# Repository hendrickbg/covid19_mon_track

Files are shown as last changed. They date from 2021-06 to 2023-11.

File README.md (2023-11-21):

# Covid-19 Vaccine Monitoring and Tracking using iMCP HT32SX - Undergraduate Thesis

- Pontifical Catholic University of Rio Grande do Sul - Brazil <br/>
Computer Engineering Undergraduate Thesis  

- Author: Hêndrick Bataglin Gonçalves
- Year: 2021/1

<hr>

## Project

Undergraduate Thesis developed using [iMCP HT32SX](https://github.com/htmicron/ht32sx) and BlueNRG-LP.

<hr>

## How to Clone this Repository

```
git clone git@github.com:HendrickGoncalves/covid19_mon_track.git
```

<hr>

## Hyper Links:

* [Firmware Project](Firmware_Project);
* [Hardware_Project](Hardware_Project).
* [Monograph](TCC-Monograph.pdf)

<hr>

## Contact

Email: hendrick.goncalves2019@gmail.com \
LinkedIn: https://www.linkedin.com/in/hendrick-goncalves/

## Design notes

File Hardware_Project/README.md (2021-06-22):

# Hardware Documents

<div align="center">
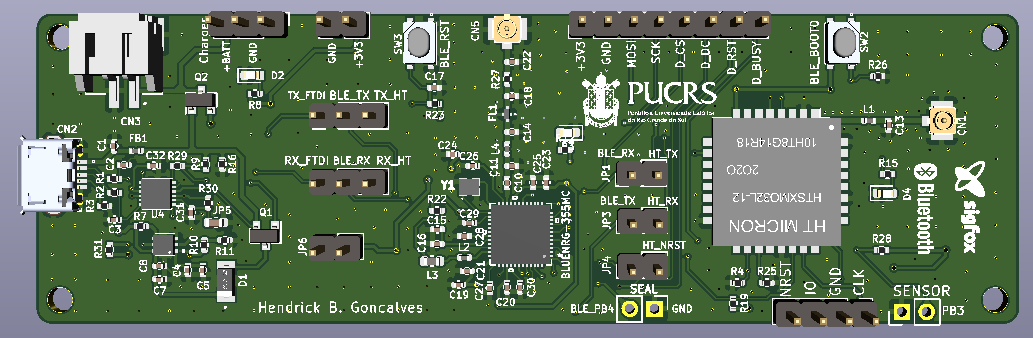
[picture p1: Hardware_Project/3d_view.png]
  
</div>
<div align="center"> Figure 1 - PCB 3D View. </div>

<hr>

Hyper links:

* [PCB Schematic](Schematic.pdf);
* [Gerber Files](Gerber_Files);
* [Centroid Files](Centroid_Files).
* [BOM](BOM/BOM.xlsx)

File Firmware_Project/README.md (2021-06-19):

# Firmware Project

* [iMCP HT32SX Firmware](HT32SX_Firmware/AT_Commands);
* [BlueNRG-LP Firmware](Vaccine_Tracker_BLE).

<hr>

## Software and IDE

* **Keil uVision:** BlueNRG-LP development;
* **STM32CubeIDE:** iMCP HT32SX development.

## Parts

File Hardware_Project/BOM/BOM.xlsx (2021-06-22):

Item | Designator | Quantity | Value | Manufacturer | MPN | Description | Footprint | Type
1 | C1 C17 | 2 | 10nF | Murata | GCM155R71H103KA55J | Multilayer Ceramic Capacitor 10nF, 10%, 50V | Capacitor_SMD:C_0402_1005Metric | SMD
2 | C10 | 1 | 3.4pF | Murata | GCQ1555C1H3R4CB01D | Multilayer Ceramic Capacitor 3.4pF, 0.25 pF tolerance, 50V | Capacitor_SMD:C_0402_1005Metric | SMD
3 | C11 | 1 | 1.2pF | Murata | GRM1555C1E1R2BA01D | Multilayer Ceramic Capacitor 1.2pF, 0.1pF tolerance, 25V | Capacitor_SMD:C_0402_1005Metric | SMD
4 | C13 | 1 | 4.7pF | Murata | GRM1555C1H4R7WA01D | Multilayer Ceramic Capacitor 0.5pF, 0.05pF tolerance, 50V | Capacitor_SMD:C_0402_1005Metric | SMD
5 | C14 | 1 | 0.5pF | Murata | GCQ1555C1HR50WB01D | Multilayer Ceramic Capacitor 0.5pF, 0.05pF tolerance, 50V | Capacitor_SMD:C_0402_1005Metric | SMD
6 | C15 C19 | 2 | 4.7uF | Murata | GRT155C80J475ME13D | Multilayer Ceramic Capacitor 4.7uF, 20% tolerance, 6.3V | Capacitor_SMD:C_0402_1005Metric | SMD
7 | C18 C22 | NA | NON POPULATED | NON POPULATED | NON POPULATED | NON POPULATED | NON POPULATED | NON POPULATED
8 | C2 C3 | 2 | 47pF | Murata | GCM1555C1H470JA16J | Multilayer Ceramic Capacitor 47pF, 5%, 50V | Capacitor_SMD:C_0402_1005Metric | SMD
9 | C25 C26 | 2 | 3pF | Murata | GRM1555C1H3R0BA01J | Multilayer Ceramic Capacitor 3pF, 0.1pF tolerance, 10V | Capacitor_SMD:C_0402_1005Metric | SMD
10 | C28 | 1 | 220nF | Murata | GRM155R61A224KE19D | Multilayer Ceramic Capacitor 220nF, 10%, 50V | Capacitor_SMD:C_0402_1005Metric | SMD
11 | C4 C8 C16 C20 C21 C23 C24 C27 C29 C30 C31 C32 | 12 | 100nF | Murata | GCM155L8EH104KE07D | Multilayer Ceramic Capacitor 100nF, 10%, 50V | Capacitor_SMD:C_0402_1005Metric | SMD
12 | C5 C7 | 2 | 1uF | Murata | GRM155R61E105KA12D | Multilayer Ceramic Capacitor 1uF, 10%, 25V, X5R | Capacitor_SMD:C_0402_1005Metric | SMD
13 | CN1 CN5 | 2 | 50ohms | Linx Technologies | CONUFL001-SMD | UFL connector 50Ohms | NA | SMD
14 | CN2 | 1 | NA | Amphenol ICC (FCI) | 10118194-0001LF | Micro USB 2.0 Connector | NA | PTH
15 | CN3 | 1 | NA | JST | S2B-PH-SM4-TB(LF)(SN) | PH 2.0 2 pin connector | NA | SMD
16 | Seal_Connector1 | NA | NON POPULATED | NON POPULATED | NON POPULATED | NON POPULATED | NON POPULATED | NON POPULATED
17 | AD_Connector1 | NA | NON POPULATED | NON POPULATED | NON POPULATED | NON POPULATED | NON POPULATED | NON POPULATED
18 | CN4 | 1 | NA | Harwin | M20-9770246 | Connector PinHeader 2.54mm 1x2 Vertical | NA | PTH
19 | D1 | 1 | NA | ON Semiconductor | MBR120LSFT3G | Shottky Diode Rectifier 1A 20V | SOD-123FL | SMD
20 | D2 | 1 | NA | Rohm Semiconductor | SMLE12WBC7W1 | Standard LEDs - SMD 0603 White Led | 0603_1608Metric | SMD
21 | D3 D4 | 2 | NA | Inolux | IN-S63AT5B | Standard LEDs - SMD 0603 Blue Led | 0603_1608Metric | SMD
22 | Display_Connector1 | 1 | NA | Harwin | M20-9770846 | Connector PinHeader 2.54mm 1x8 Vertical | NA | PTH
23 | FB1 | 1 | 30ohms | Murata | BLM15AX300SN1D | Ferrite Bead 30ohms 1.1A, 25% tolerance | Inductor_SMD:L_0402_1005Metric | SMD
24 | FL1 | 1 | 50ohms | Johanson Technology | 2450LP07C0100 | Signal Conditioning Low Pass Filter 2.4GHz Mini | 0402_1005Metric | SMD
25 | HT_SWD_CONNECTOR1 | 1 | NA | Harwin | M20-9770446 | Connector PinHeader 2.54mm 1x4 Vertical | NA | PTH
26 | JP1 JP3 JP4 JP6 | 4 | NA | Harwin | M20-9770246 | Connector PinHeader 2.54mm 1x2 Vertical | NA | PTH
27 | JP5 | 1 | NA | NON POPULATED | NON POPULATED | NON POPULATED | NON POPULATED | NON POPULATED
28 | L1 | 1 | 5.6nH | Murata | LQW15AN5N6B8ZD | Fixed Inductor 5.6nH, 40mOhms, 1.77A | Inductor_SMD:L_0402_1005Metric | SMD
29 | L2 | 1 | 22nH | Murata | LQP02TN22NJ02D | Fixed Inductor 22nH, 5Ohms, 120mA | Inductor_SMD:L_0402_1005Metric | SMD
30 | L3 | 1 | 10uH | Murata | LQM18FN100M00D | Fixed Inductor 10uH, 1.17Ohms, 50mA | Inductor_SMD:L_0603_1608Metric | SMD
31 | L4 | 1 | 3nH | Murata | LQP15MN3N0B02D | Fixed Inductor 3nH, 500mOhms, 190mA | Inductor_SMD:L_0402_1005Metric | SMD
32 | Q1 Q2 | 2 | NA | Infineon Technologies | IRLML6402TRPBF | MOSFET P-CH 3.7A 65mOhm | SOT23-3 | SMD
33 | R1 R2 | 2 | 27 | Yageo | RT0402FRE0727KL | Thin film resistor, 27ohms, 1%, 50V | Resistor_SMD:R_0402_1005Metric | SMD
34 | R4 R10 R19 R23 R25 R26 R28 R31 | 8 | 10K | Yageo | RT0402FRE0710KL | Thin film resistor, 10kohms, 1%, 50V | Resistor_SMD:R_0402_1005Metric | SMD
35 | R11 | 1 | 2K | Yageo | RT0402FRE072KL | Thin film resistor, 2kohms, 1%, 50V | Resistor_SMD:R_0402_1005Metric | SMD
36 | R8 R12 R15 R29 | 4 | 1K | Yageo | RT0402FRE071KL | Thin film resistor, 4kohms, 1%, 50V | Resistor_SMD:R_0402_1005Metric | SMD
37 | R22 | NA | NON POPULATED | NON POPULATED | NON POPULATED | NON POPULATED | NON POPULATED | NON POPULATED
38 | R27 | 1 | 0 | Yageo | PT0402-R-070RL | Thin film resistor, 10kohms, 1%, 50V | Resistor_SMD:R_0402_1005Metric | SMD
39 | R3 R7 R9 R16 R30 | 5 | 100K | Yageo | RT0402FRE07100KL | Thin film resistor, 100kohms, 1%, 50V | Resistor_SMD:R_0402_1005Metric | SMD
40 | SW2 | 1 | NA | C&K | PTS815 SJK 250 SMTR LFS | Tactile switch SPST-NO Top actuated surface mount, color white | NA | SMD
41 | SW3 | 1 | NA | C&K | PTS810 SJG 250 SMTR LFS | Tactile switch SPST-NO Top actuated surface mount, color blue | NA | SMD
42 | TX_Header1 RX_Header1 Charger | 3 | NA | Sullins Connector Solutions | PREC002SAAN-RC | Connector PinHeader 2.54mm 1x3 Vertical | NA | PTH
43 | U1 | NA | NON POPULATED | NON POPULATED | NON POPULATED | NON POPULATED | NON POPULATED | NON POPULATED
44 | U2 | 1 | NA | STMicroelectronics | BLUENRG-355MC | Bluenrg-LP QFN48 | NA | SMD
45 | U3 | 1 | NA | Texas Instruments | TPS73533DRVT | Voltage regulator IC | WSON-6 | SMD
46 | U4 | 1 | NA | FTDI | FT234XD-R | USB to serial converter IC | DFN-12 | SMD
47 | Y1 | 1 | 32MHz | ECS | ECS-320-10-37B-CKY-TR | CRYSTAL 32.0000MHZ 10PF 50ohms SMD | NA | SMD

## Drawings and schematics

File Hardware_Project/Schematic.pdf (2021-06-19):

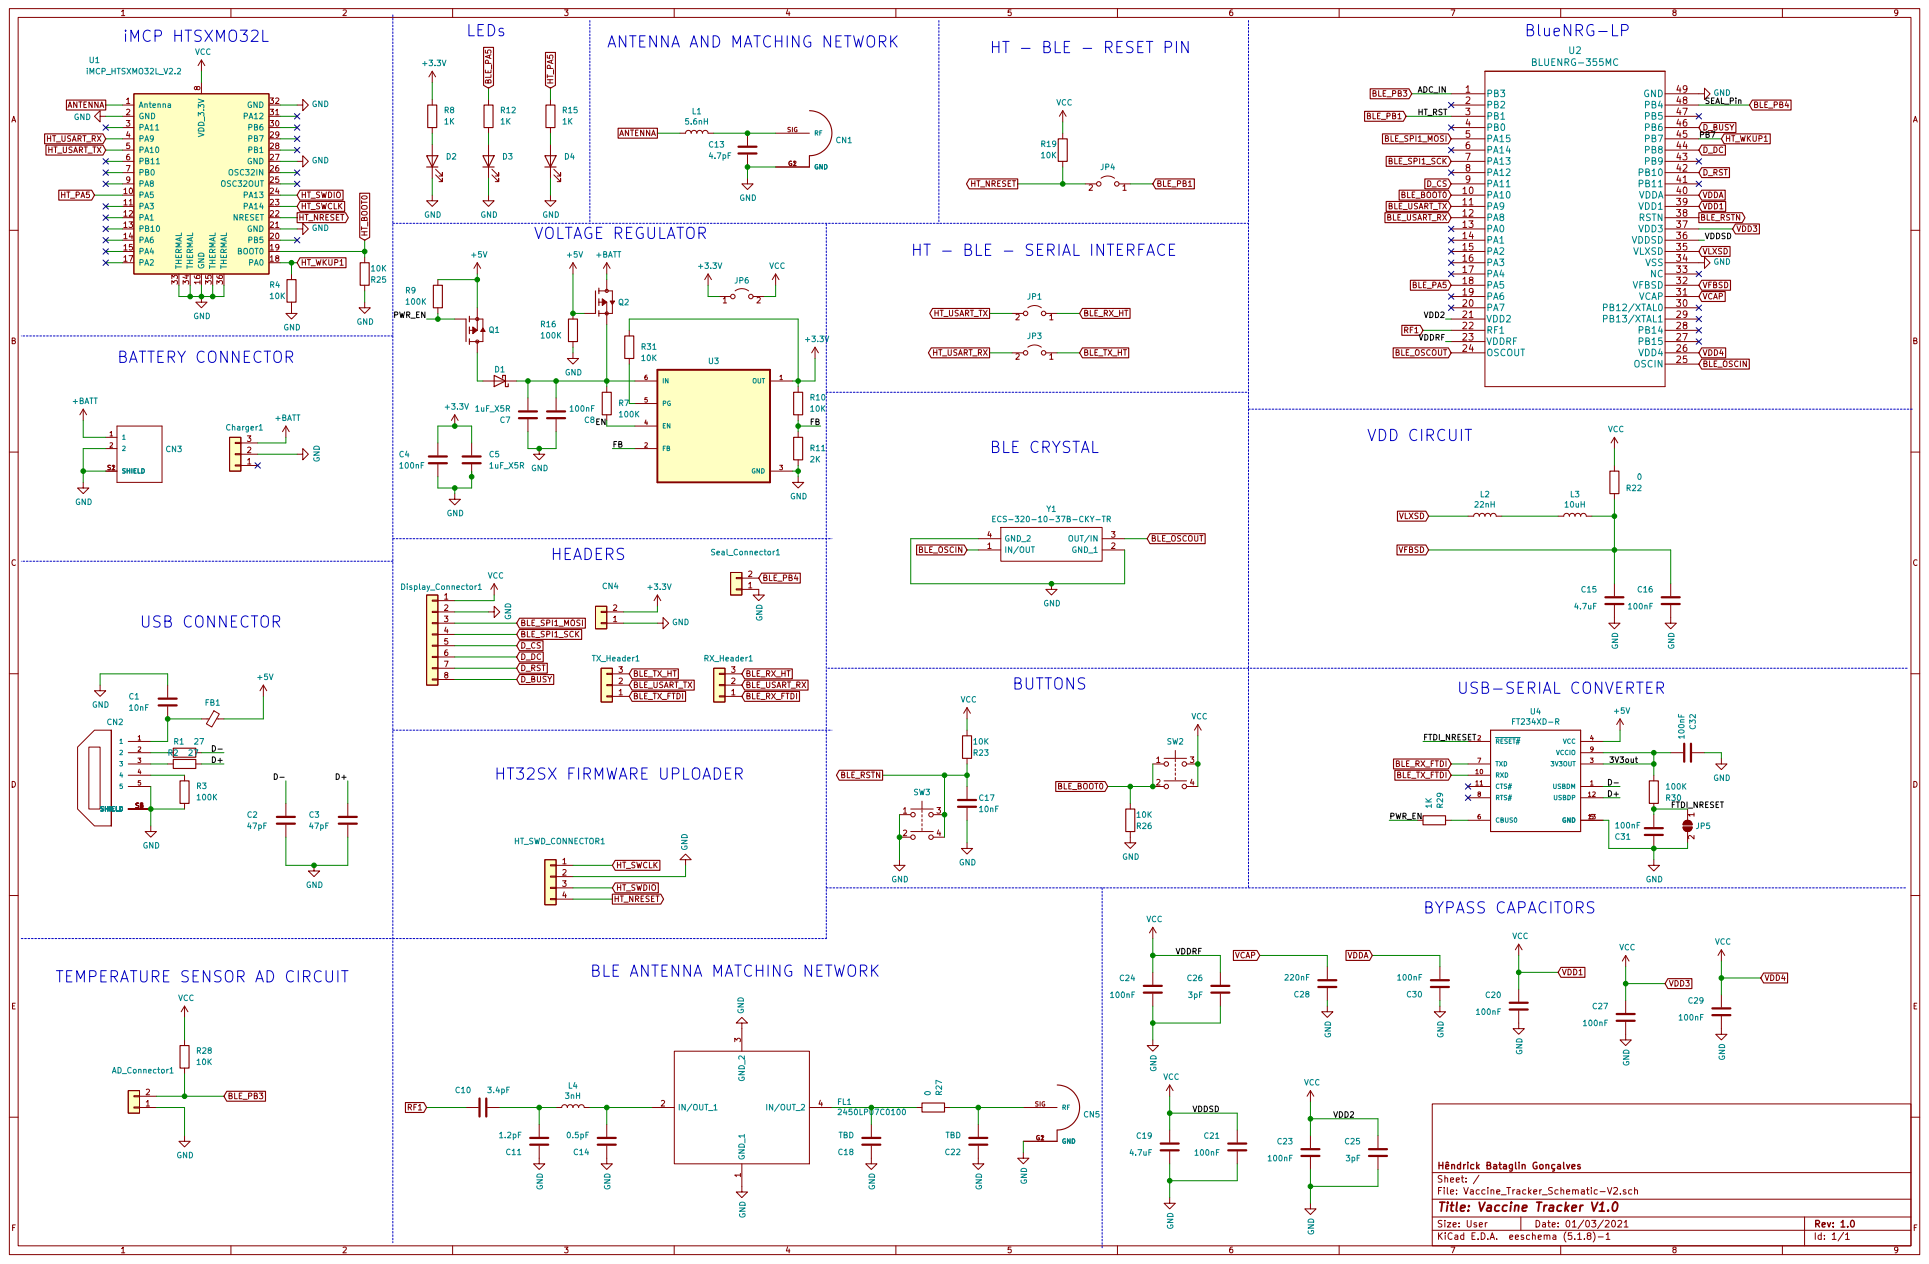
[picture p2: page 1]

HT - BLE - SERIAL INTERFACE

BLE ANTENNA MATCHING NETWORK TEMPERATURE SENSOR AD CIRCUIT

File: Vaccine_Tracker_Schematic-V2.sch Sheet: / Hêndrick Bataglin Gonçalves C21

Id: 1/1 Title: Vaccine Tracker V1.0

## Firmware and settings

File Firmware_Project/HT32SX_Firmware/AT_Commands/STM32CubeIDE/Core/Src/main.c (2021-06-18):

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

/* Includes ------------------------------------------------------------------*/
#include "main.h"
#include "adc.h"
#include "dma.h"
#include "rtc.h"
#include "spi.h"
#include "tim.h"
#include "usart.h"
#include "gpio.h"

/* USER CODE BEGIN Includes */
#include "SDK_UTILS_Flash.h"
#include "HT_mcu_api.h"
/* USER CODE END Includes */


void SystemClock_Config(void);
/**
 * @brief  The application entry point.
 * @retval int
 */
int main(void)
{
	/* MCU Configuration--------------------------------------------------------*/

	/* Reset of all peripherals, Initializes the Flash interface and the Systick. */
	HAL_Init();

	/* Configure the system clock */
	SystemClock_Config();

	/* Initialize all configured peripherals */
	MX_GPIO_Init();
	MX_DMA_Init();
	MX_RTC_Init();
	MX_SPI1_Init();
	MX_TIM6_Init();
	MX_USART1_UART_Init();
	MX_ADC_Init();
	MX_TIM2_Init();
	MX_TIM21_Init();
	MX_TIM22_Init();
	MX_USART2_UART_Init();
	/* USER CODE BEGIN 2 */

	GPIOA->BSRR = 1 << 5;

	__HAL_TIM_CLEAR_FLAG(&htim22, TIM_FLAG_UPDATE);
	HAL_TIM_Base_Start_IT(&htim22);

	mcuConfig();

	/* USER CODE END 2 */

	/* Infinite loop */
	/* USER CODE BEGIN WHILE */
	while (1)
	{
		/* USER CODE END WHILE */

		/* USER CODE BEGIN 3 */
		HT_hcfsm();
	}
	/* USER CODE END 3 */
}

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
/* USER CODE BEGIN 4 */

void mcuConfig(void) {

	ST_SFX_ERR stSfxRetErr;

	ST_Init();

	NVM_BoardDataType sfxConfiguration;
	stSfxRetErr = ST_Sigfox_Init(&sfxConfiguration, 0);

	if(stSfxRetErr != ST_SFX_ERR_NONE) {
		if(stSfxRetErr == ST_SFX_ERR_CREDENTIALS) {
			sfxConfiguration.id = 0;
			memset(sfxConfiguration.pac, 0x00, 8);
			sfxConfiguration.rcz = 0;

		}
	}

	printUart("HT3\n");

	/* Calibrate RTC in case of STM32*/
	ST_MCU_API_TimerCalibration(500);

	ST_RF_API_set_xtal_freq(50000000); 
	ST_RF_API_set_freq_offset(sfxConfiguration.freqOffset);
	ST_RF_API_set_rssi_offset(sfxConfiguration.rssiOffset);
	ST_RF_API_set_lbt_thr_offset(sfxConfiguration.lbtOffset);
}

void ST_Init(void) {
	/* Put the radio off */
	S2LPShutdownInit();
	HAL_Delay(10);
	S2LPShutdownExit();

	/* FEM Initialization */
	FEM_Init();
}

/* USER CODE END 4 */
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


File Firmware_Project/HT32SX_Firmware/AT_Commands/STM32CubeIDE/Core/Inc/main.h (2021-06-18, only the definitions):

#define USE_DMA_CIRCULAR 1
#define S2LP_SPI_CS_PIN_Pin GPIO_PIN_15
#define S2LP_SPI_CS_PIN_GPIO_Port GPIOA
#define S2LP_SPI_MISO_PIN_Pin GPIO_PIN_4
#define S2LP_SPI_MISO_PIN_GPIO_Port GPIOB
#define S2LP_SPI_SCLK_PIN_Pin GPIO_PIN_3
#define S2LP_SPI_SCLK_PIN_GPIO_Port GPIOB
#define S2LP_SPI_MOSI_PIN_Pin GPIO_PIN_7
#define S2LP_SPI_MOSI_PIN_GPIO_Port GPIOA
#define ALL_REGIONS 127
#define RCZ1_OUTPUT_POWER 	-32
#define RCZ2_OUTPUT_POWER	-27
#define RCZ3_OUTPUT_POWER	-32
#define RCZ4_OUTPUT_POWER	-27
#define RCZ5_OUTPUT_POWER	-32
#define RCZ6_OUTPUT_POWER	-32
#define RCZ7_OUTPUT_POWER	-32

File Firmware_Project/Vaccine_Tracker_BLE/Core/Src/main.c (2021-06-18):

/*****************************************************************************
* File Name          : main.c
* Author             : Hêndrick Bataglin Gonçalves
* Version            : V1.0.0
* Date               : 10-April-2021
* Description        : Vaccine Tracker main file.
*******************************************************************************/

#include "main.h"
#include "HT_ble_api.h"

NO_INIT(uint32_t dyn_alloc_a[DYNAMIC_MEMORY_SIZE >> 2]);

extern WakeupSourceConfig_TypeDef wakeupIO;
extern PowerSaveLevels stopLevel;

int main(void) {

  /* System initialization function */
  if (SystemInit(SYSCLK_64M, BLE_SYSCLK_32M) != SUCCESS)
    while (1);

  HAL_Init();

  /* Configure IOs for power save modes */
  MX_GPIO_LP_Init();

  ModulesInit();

  MX_GPIO_Init();
  MX_USART1_UART_Init();
  MX_ADC_Init();
  MX_DMA_Init();
  MX_TIM1_Init();
  MX_SPI1_Init();
  MX_RTC_Init();

  printf("Vaccine Tracker Application.\n");
  
  HT_BLE_BleConfig();

  HT_BLE_SetDeviceConnectable();
  HT_APP_ConfigWakeupIO();

  while (1) {

    ModulesTick();
    HT_app();
    //HT_APP_DeepSleepState();
  }
}

void ModulesInit(void) {
  uint8_t ret;
  BLE_STACK_InitTypeDef BLE_STACK_InitParams = BLE_STACK_INIT_PARAMETERS;

  LL_AHB_EnableClock(LL_AHB_PERIPH_PKA | LL_AHB_PERIPH_RNG);

  /* BlueNRG-LP stack init */
  ret = BLE_STACK_Init(&BLE_STACK_InitParams);
  if (ret != BLE_STATUS_SUCCESS)
    while (1);

  HAL_VTIMER_InitType VTIMER_InitStruct = {HS_STARTUP_TIME, INITIAL_CALIBRATION, CALIBRATION_INTERVAL};
  HAL_VTIMER_Init(&VTIMER_InitStruct);

  BLEPLAT_Init();
}

void ModulesTick(void) {
  /* Timer tick */
  HAL_VTIMER_Tick();

  /* Bluetooth stack tick */
  BLE_STACK_Tick();

  /* NVM manager tick */
  NVMDB_Tick();
}

PowerSaveLevels App_PowerSaveLevel_Check(PowerSaveLevels level) {
  return POWER_SAVE_LEVEL_STOP_WITH_TIMER;
}

void hci_hardware_error_event(uint8_t Hardware_Code) {
  if (Hardware_Code <= 0x03)
    NVIC_SystemReset();
}

void aci_hal_fw_error_event(uint8_t FW_Error_Type, uint8_t Data_Length, uint8_t Data[]) {
  if (FW_Error_Type <= 0x03) {
    uint16_t connHandle;

    /* Data field is the connection handle where error has occurred */
    connHandle = LE_TO_HOST_16(Data);

    aci_gap_terminate(connHandle, BLE_ERROR_TERMINATED_REMOTE_USER);
  }
}

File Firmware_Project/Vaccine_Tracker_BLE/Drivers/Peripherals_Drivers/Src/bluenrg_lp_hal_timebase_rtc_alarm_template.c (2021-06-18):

/**
  ******************************************************************************
  * @file    bluenrg_lp_hal_timebase_rtc_alarm_template.c 
  * @author  RF Application Team
  * @brief   HAL time base based on the hardware RTC_ALARM Template.
  *
  *          This file override the native HAL time base functions (defined as weak)
  *          to use the RTC ALARM for time base generation:
  *           + Intializes the RTC peripheral to increment the seconds registers each 1ms
  *           + The alarm is configured to assert an interrupt when the RTC reaches 1ms 
  *           + HAL_IncTick is called at each Alarm event and the time is reset to 00:00:00
  *           + HSE (default), LSE or LSI can be selected as RTC clock source  
 @verbatim
  ==============================================================================
                        ##### How to use this driver #####
  ==============================================================================
    [..]
    This file must be copied to the application folder and modified as follows:
    (#) Rename it to 'bluenrg_lp_hal_timebase_rtc_alarm.c'
    (#) Add this file and the RTC HAL drivers to your project and uncomment
       HAL_RTC_MODULE_ENABLED define in bluenrg_lp_hal_conf.h 

    [..]
    (@) HAL RTC alarm and HAL RTC wakeup drivers can’t be used with low power modes:
        The wake up capability of the RTC may be intrusive in case of prior low power mode
        configuration requiring different wake up sources.
        Application/Example behavior is no more guaranteed 
    (@) The bluenrg_lp_hal_timebase_tim use is recommended for the Applications/Examples
          requiring low power modes

  @endverbatim
  ******************************************************************************
  * @attention
  *
  * <h2><center>&copy; Copyright (c) 2018 STMicroelectronics. 
  * All rights reserved.</center></h2>
  *
  * This software component is licensed by ST under BSD 3-Clause license,
  * the "License"; You may not use this file except in compliance with the 
  * License. You may obtain a copy of the License at:
  *                        opensource.org/licenses/BSD-3-Clause
  *
  ******************************************************************************
  */

/* Includes ------------------------------------------------------------------*/
#include "bluenrg_lp_hal.h"
/** @addtogroup BLUENRG_LP_HAL_Driver
  * @{
  */

/** @defgroup HAL_TimeBase_RTC_Alarm_Template  HAL TimeBase RTC Alarm Template
  * @{
  */ 

/* Private typedef -----------------------------------------------------------*/
/* Private define ------------------------------------------------------------*/

/* Uncomment the line below to select the appropriate RTC Clock source for your application: 
  + RTC_CLOCK_SOURCE_LSE: can be selected for applications with low constraint on timing
                          precision.
  + RTC_CLOCK_SOURCE_LSI: can be selected for applications with low constraint on timing
                          precision.
  */
#define RTC_CLOCK_SOURCE_LSE
/* #define RTC_CLOCK_SOURCE_LSI */

#define RTC_ASYNCH_PREDIV       0U
#define RTC_SYNCH_PREDIV        31U

/* Private macro -------------------------------------------------------------*/
/* Private variables ---------------------------------------------------------*/
extern RTC_HandleTypeDef hRTC_Handle;
//RTC_HandleTypeDef hRTC_Handle;

/* Private function prototypes -----------------------------------------------*/
void RTC_Alarm_IRQHandler(void);
/* Private functions ---------------------------------------------------------*/

/**
  * @brief  This function configures the RTC_ALARMA as a time base source. 
  *         The time source is configured  to have 1ms time base with a dedicated 
  *         Tick interrupt priority. 
  * @note   This function is called  automatically at the beginning of program after
  *         reset by HAL_Init() or at any time when clock is configured, by HAL_RCC_ClockConfig().
  * @param  TickPriority: Tick interrupt priority.
  * @retval HAL status
  */
HAL_StatusTypeDef HAL_InitTick (uint32_t TickPriority)
{
  __IO uint32_t counter = 0U;

  RCC_OscInitTypeDef        RCC_OscInitStruct;

#ifdef RTC_CLOCK_SOURCE_LSE
  /* Configue LSE as RTC clock soucre */
  RCC_OscInitStruct.OscillatorType = RCC_OSCILLATORTYPE_LSE;
  RCC_OscInitStruct.LSEState = RCC_LSE_ON;
#elif defined (RTC_CLOCK_SOURCE_LSI)
  /* Configue LSI as RTC clock soucre */
  RCC_OscInitStruct.OscillatorType = RCC_OSCILLATORTYPE_LSI1;
  RCC_OscInitStruct.LSIState = RCC_LSI_ON;
#else
#error Please select the RTC Clock source
#endif /* RTC_CLOCK_SOURCE_LSE */

  if(HAL_RCC_OscConfig(&RCC_OscInitStruct) == HAL_OK)
  {
    /* Enable RTC Clock */
    __HAL_RCC_RTC_CLK_ENABLE();
    /* The time base should be 1ms
       Time base = ((RTC_ASYNCH_PREDIV + 1) * (RTC_SYNCH_PREDIV + 1)) / RTC_CLOCK 
       HSE as RTC clock 
       Time base = ((99 + 1) * (9 + 1)) / 1MHz
       = 1ms
       LSE as RTC clock 
       Time base = ((31 + 1) * (0 + 1)) / 32.768KHz
       = ~1ms
       LSI as RTC clock 
       Time base = ((31 + 1) * (0 + 1)) / 32KHz
       = 1ms
    */
    hRTC_Handle.Instance = RTC;
    hRTC_Handle.Init.HourFormat = RTC_HOURFORMAT_24;
    hRTC_Handle.Init.AsynchPrediv = RTC_ASYNCH_PREDIV;
    hRTC_Handle.Init.SynchPrediv = RTC_SYNCH_PREDIV;
    hRTC_Handle.Init.OutPut = RTC_OUTPUT_DISABLE;
    hRTC_Handle.Init.OutPutPolarity = RTC_OUTPUT_POLARITY_HIGH;
    if (HAL_RTC_Init(&hRTC_Handle) != HAL_OK)
      {
        return HAL_ERROR;
      }

    /* Disable the write protection for RTC registers */
    __HAL_RTC_WRITEPROTECTION_DISABLE(&hRTC_Handle);

    /* Disable the Alarm A interrupt */
    __HAL_RTC_ALARMA_DISABLE(&hRTC_Handle);

    /* Clear flag alarm A */
    __HAL_RTC_ALARM_CLEAR_FLAG(&hRTC_Handle, RTC_FLAG_ALRAF);

    counter = 0U;
    /* Wait till RTC ALRAWF flag is set and if Time out is reached exit */
    while(__HAL_RTC_ALARM_GET_FLAG(&hRTC_Handle, RTC_FLAG_ALRAWF) == 0U)
      {
        if(counter++ == (SystemCoreClock /48U)) /* Timeout = ~ 1s */
          {
            return HAL_ERROR;
          }
      }

    hRTC_Handle.Instance->ALRMAR = (uint32_t)0x01U;

    /* Configure the Alarm state: Enable Alarm */
    __HAL_RTC_ALARMA_ENABLE(&hRTC_Handle);
    /* Configure the Alarm interrupt */
    __HAL_RTC_ALARM_ENABLE_IT(&hRTC_Handle, RTC_IT_ALRA);

    /* Check if the Initialization mode is set */
    if((hRTC_Handle.Instance->ISR & RTC_ISR_INITF) == (uint32_t)RESET)
      {
        /* Set the Initialization mode */
        hRTC_Handle.Instance->ISR = (uint32_t)RTC_INIT_MASK;
        counter = 0U;
        while((hRTC_Handle.Instance->ISR & RTC_ISR_INITF) == (uint32_t)RESET)
          {
            if(counter++ == (SystemCoreClock /48U)) /* Timeout = ~ 1s */
              {
                return HAL_ERROR;
              }
          }
      }
    hRTC_Handle.Instance->DR = 0U;
    hRTC_Handle.Instance->TR = 0U;
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

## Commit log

2021-06-19 updating rep tree
    [Vaccine_Layout_V2-B_Cu.gbl, Vaccine_Layout_V2-B_Mask.gbs, Vaccine_Layout_V2-Edge_Cuts.gm1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]
2021-06-22 added BOM file.
    [BOM.xlsx]
2021-06-28 added pcb firmware version

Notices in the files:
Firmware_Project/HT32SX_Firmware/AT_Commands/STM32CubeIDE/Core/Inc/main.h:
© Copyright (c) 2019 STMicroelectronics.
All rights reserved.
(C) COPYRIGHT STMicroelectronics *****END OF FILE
